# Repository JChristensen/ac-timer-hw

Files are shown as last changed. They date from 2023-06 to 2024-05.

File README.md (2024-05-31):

# AC timer  
https://github.com/JChristensen/ac-timer-hw  
README file  
Jack Christensen  
Jul-2023

## License
  
This work is licensed under the [Creative Commons Attribution-ShareAlike 4.0 International License](https://creativecommons.org/licenses/by-sa/4.0/).

## See also
[https://github.com/JChristensen/dehumid](https://github.com/JChristensen/dehumid) (firmware)  
[https://github.com/JChristensen/ac-timer-panel](https://github.com/JChristensen/ac-timer-panel)

## Construction
The project is assembled in a square metallic electrical box, 4 in. x 2⅛ in. deep (30.3 cu. in.), with ½ in. knockouts. The box acts as a heat sink for the solid state relay; use heat sink grease when fastening the SSR to the box.

See the links above for firmware and for a small PCB to facilitate mounting the LEDs and pushbutton switch.

See the bill of materials [in this repo](https://github.com/JChristensen/ac-timer-hw/blob/master/bom.csv) and at [Mouser Electronics](https://www.mouser.com/ProjectManager/ProjectDetail.aspx?AccessID=c48290707f).

## Sample assembly




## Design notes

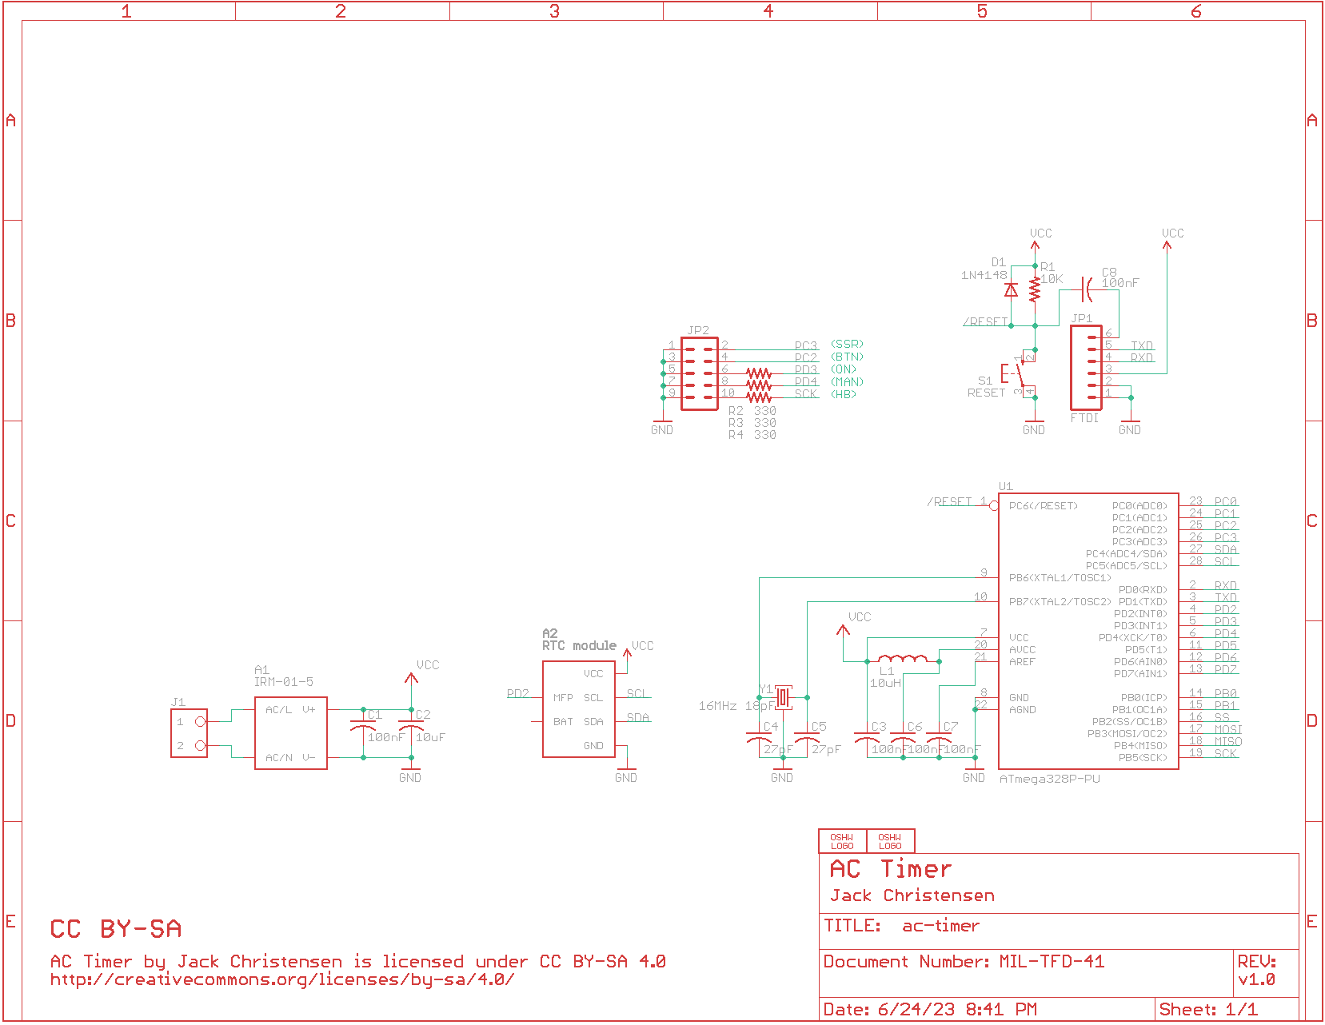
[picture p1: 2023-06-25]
schematic.png

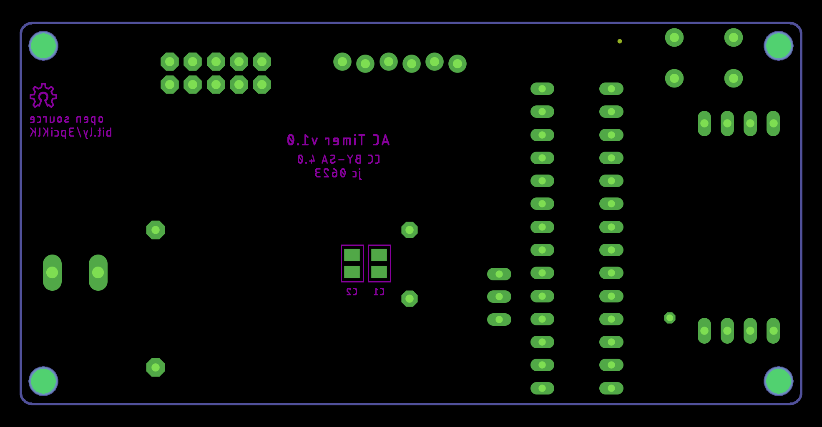
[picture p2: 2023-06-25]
bottomsilkmask.png

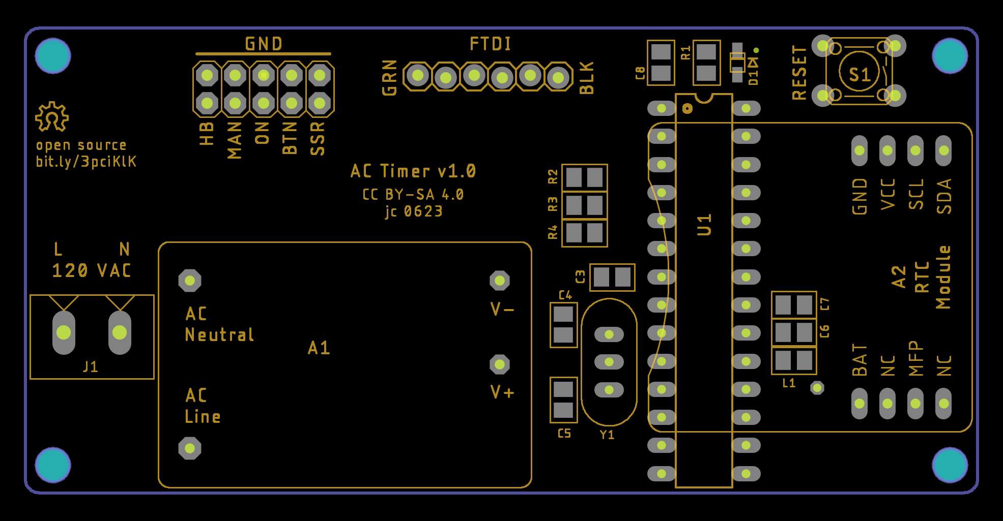
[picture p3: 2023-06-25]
topsilkmask.png

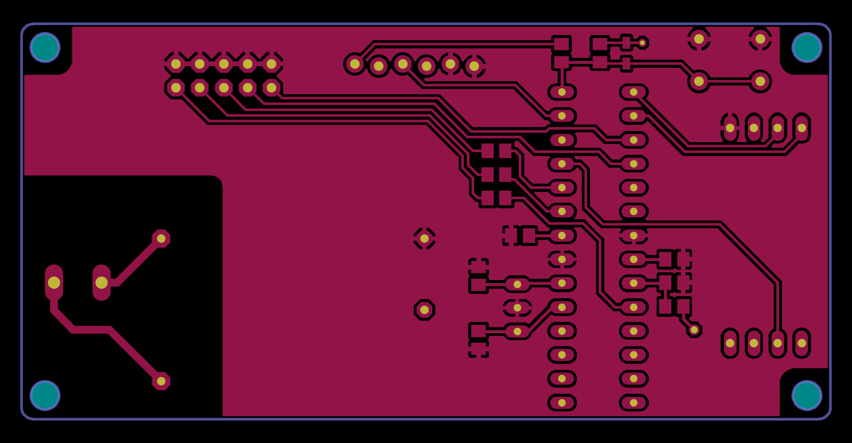
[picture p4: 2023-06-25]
toplayer.png

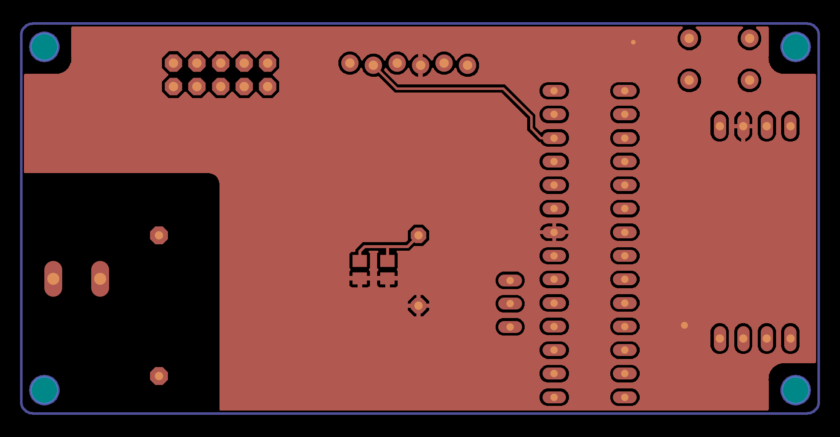
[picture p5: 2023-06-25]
bottomlayer.png

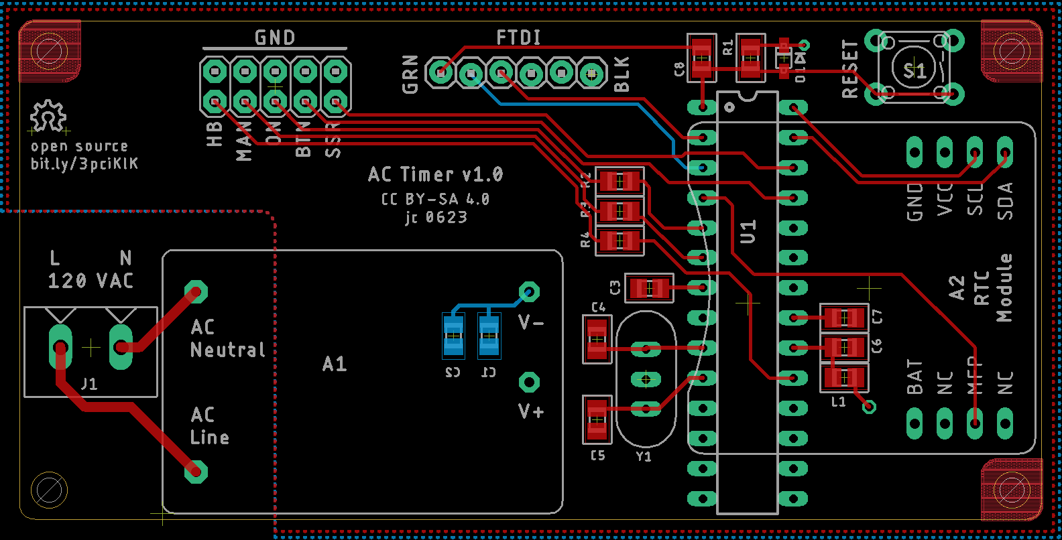
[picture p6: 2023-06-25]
board.png

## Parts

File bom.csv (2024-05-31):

AC Daily Timer
Copyright (C) 2023-2024 by Jack Christensen and licensed under CC-BY-SA-4.0.
https://www.mouser.com/ProjectManager/ProjectDetail.aspx?AccessID=c48290707f
Part # | Qty | Mouser # | Description | Manufacturer | Mfr. #
A1 | 1 | 709-IRM01-5 | AC/DC Power Module 1W 5V 200mA | MEAN WELL | IRM-01-5
A2 | 1 | n/a | Real-time clock module | JChristensen | https://github.com/JChristensen/rtc79412
C1,3,6,7,8 | 5 | 581-08053C104KAT4A | MLCC 25V 0.1uF 0805 | KYOCERA AVX | 08053C104KAT4A
C2 | 1 | 187-CL21A106KPCLQNC | MLCC 10uF 10V 0805 | Samsung Electro-Mechanics | CL21A106KPCLQNC
C4,5 | 2 | 77-VJ0805A270GXXPBC | MLCC 0805 27pF 25volts C0G 2% | Vishay | VJ0805A270GXXPW1BC
D1 | 1 | 512-1N4148WS | Small Signal Diode | onsemi | 1N4148WS
J1 | 1 | 651-1935161 | Terminal block, 2 position, 5.08mm pitch | Phoenix Contact | 1935161
JP1 | 1 |  | 2.54mm header, male, 1x6 | generic
JP2 | 1 |  | 2.54mm header, male, 2x5 | generic
L1 | 1 | 963-LBR2012T100K | Inductor 0805 10uH | TAIYO YUDEN | LBR2012T100K
R1 | 1 | 660-RK73H1JTTDD1002F | Thick Film Resistor 10k ohms | KOA Speer | RK73H1JTTDD1002F
R2,3,4 | 3 | 660-RK73H1JTTDD3300F | Thick Film Resistor 330 ohms | KOA Speer | RK73H1JTTDD3300F
S1 | 1 | 653-B3F-1020 | Tactile Button Switch | Omron | B3F-1020
U1 | 1 | 556-ATMEGA328P-PU | 8-bit Microcontroller | Microchip | ATMEGA328P-PU
Y1 | 1 | 774-ATS16B-E | Crystal, 16MHz 18pF 30ppm | CTS | ATS16B-E
 | 1 |  | Solid State Relay, 40A | SparkFun Electronics | COM-13015
 | 1 |  | Square metallic electrical box, 4 in. x 2⅛ in. deep (30.3 cu. in.), ½ in. knockouts
 | 1 |  | Cover for above box
 | 1 |  | Duplex receptacle
 | 1 |  | 14-gauge power cable
 | 1 |  | ½ in. cable clamp
 | 1 |  | Red LED, 5mm | generic
 | 1 |  | Yellow LED, 5mm | generic
 | 1 |  | Green LED, 5mm | generic
 | 1 |  | Pushbutton switch | generic | SparkFun COM-11992, Jameco 26623, or similar

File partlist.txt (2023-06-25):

Partlist

Exported from ac-timer.brd at 6/24/23 8:41 PM

EAGLE Version 9.6.2 Copyright (c) 1988-2020 Autodesk, Inc.

Assembly variant: 

Part     Value          Package       Library  Position (mm)         Orientation

A1       IRM-01-5       IRM-01        _jc      (12 0.5)              R0
A2       RTC module     RTC79412      _jc      (71.5 19.5)           R90
C1       100nF          M0805         _jc      (39.5 15.5)           MR90
C2       10uF           M0805         _jc      (36.5 15.5)           MR90
C3       100nF          M0805         _jc      (53 19.5)             R180
C4       27pF           M0805         _jc      (48.6 15.2)           R90
C5       27pF           M0805         _jc      (48.6 8.4)            R270
C6       100nF          M0805         _jc      (69.4 14.5)           R0
C7       100nF          M0805         _jc      (69.4 17)             R0
C8       100nF          M0805         _jc      (57.4 38.9)           R90
D1       1N4148         SOD-323F      _jc      (64.3 38.9)           R90
J1                      OST-TB-2-0.20 _jc      (6 14.5)              R180
JP1      FTDI           1X06_LOCK     SparkFun (48.14 37.5)          R180
JP2      M05X2PTH       AVR_ICSP      SparkFun (21.5 36.5)           R270
L1       10uH           M0805         _jc      (69.4 11.95)          R180
R1       10K            M0805         _jc      (61.5 38.9)           R90
R2       330            M0805         _jc      (50.5 28.5)           R180
R3       330            M0805         _jc      (50.5 26)             R180
R4       330            M0805         _jc      (50.5 23.5)           R180
S1       RESET          B3F-10XXOCT   _jc      (75.28 38.15)         R180
U1       ATmega328P-PU  DIL28-3       SparkFun (61.28 18.25)         R270
Y1       16MHz 18pF     RESONATOR     _jc      (52.71 11.82)         R270

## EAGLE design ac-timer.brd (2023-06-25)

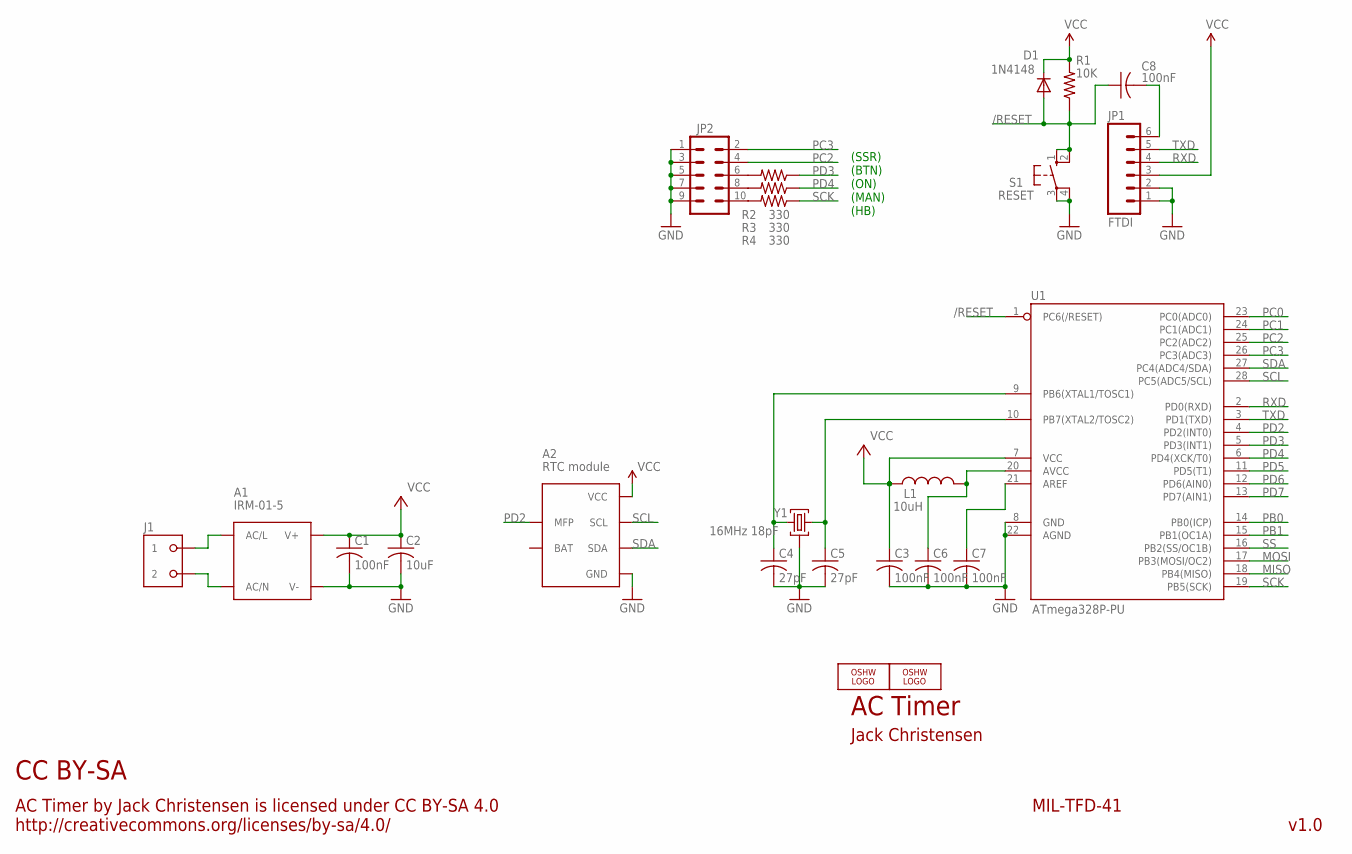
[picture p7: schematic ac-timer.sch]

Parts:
A1: IRM-01-5; IRM-01
A2: RTC module; RTC79412
C1, C3, C6, C7, C8: 100nF; M0805
C2: 10uF; M0805
C4, C5: 27pF; M0805
D1: 1N4148; SOD-323F
J1: OST-TB-20.20IN; OST-TB-2-0.20
JP1: FTDI; 1X06_LOCK
JP2: M05X2PTH; AVR_ICSP
L1: 10uH; M0805
LOGO1, LOGO2: OSHW_LOGO_8MILX0100-NT; OSHW_8X100_NOTEXT
R1: 10K; M0805
R2, R3, R4: 330; M0805
S1: RESET; B3F-10XXOCT
U1: ATmega328P-PU; DIL28-3
Y1: 16MHz 18pF; RESONATOR

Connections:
/RESET: C8.1, D1.A, R1.1, S1.1 (S), S1.2 (S1), U1.1 (PC6(/RESET))
GND: A1.V-, A2.8 (GND), C1.2, C2.2, C3.2, C4.2, C5.2, C6.2, C7.2, JP1.1, JP1.2, JP2.1, JP2.3, JP2.5, JP2.7, JP2.9, S1.3, S1.4 (P1), U1.8 (GND), U1.22 (AGND), Y1.2
MISO: U1.18 (PB4(MISO))
MOSI: U1.17 (PB3(MOSI/OC2))
unnamed: JP2.10, R4.2
unnamed: JP2.8, R3.2
unnamed: JP2.6, R2.2
unnamed: C5.1, U1.10 (PB7(XTAL2/TOSC2)), Y1.3
unnamed: C6.1, L1.2, U1.20 (AVCC)
unnamed: C4.1, U1.9 (PB6(XTAL1/TOSC1)), Y1.1
unnamed: C7.1, U1.21 (AREF)
unnamed: A1.AC/N, J1.P$2 (2)
unnamed: A1.AC/L, J1.P$1 (1)
PB0: U1.14 (PB0(ICP))
PB1: U1.15 (PB1(OC1A))
PC0: U1.23 (PC0(ADC0))
PC1: U1.24 (PC1(ADC1))
PC2: JP2.4, U1.25 (PC2(ADC2))
PC3: JP2.2, U1.26 (PC3(ADC3))
PD2: A2.3 (MFP), U1.4 (PD2(INT0))
PD3: R2.1, U1.5 (PD3(INT1))
PD4: R3.1, U1.6 (PD4(XCK/T0))
PD5: U1.11 (PD5(T1))
PD6: U1.12 (PD6(AIN0))
PD7: U1.13 (PD7(AIN1))
RST: C8.2, JP1.6
RXD: JP1.4, U1.2 (PD0(RXD))
SCK: R4.1, U1.19 (PB5(SCK))
SCL: A2.6 (SCL), U1.28 (PC5(ADC5/SCL))
SDA: A2.5 (SDA), U1.27 (PC4(ADC4/SDA))
SS: U1.16 (PB2(SS/OC1B))
TXD: JP1.5, U1.3 (PD1(TXD))
VCC: A1.V+, A2.7 (VCC), C1.1, C2.1, C3.1, D1.K, JP1.3, L1.1, R1.2, U1.7 (VCC)

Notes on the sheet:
AC Timer
Jack Christensen
AC Timer by Jack Christensen is licensed under CC BY-SA 4.0 http://creativecommons.org/licenses/by-sa/4.0/
CC BY-SA
v1.0
MIL-TFD-41
(SSR) (BTN) (ON) (MAN) (HB)

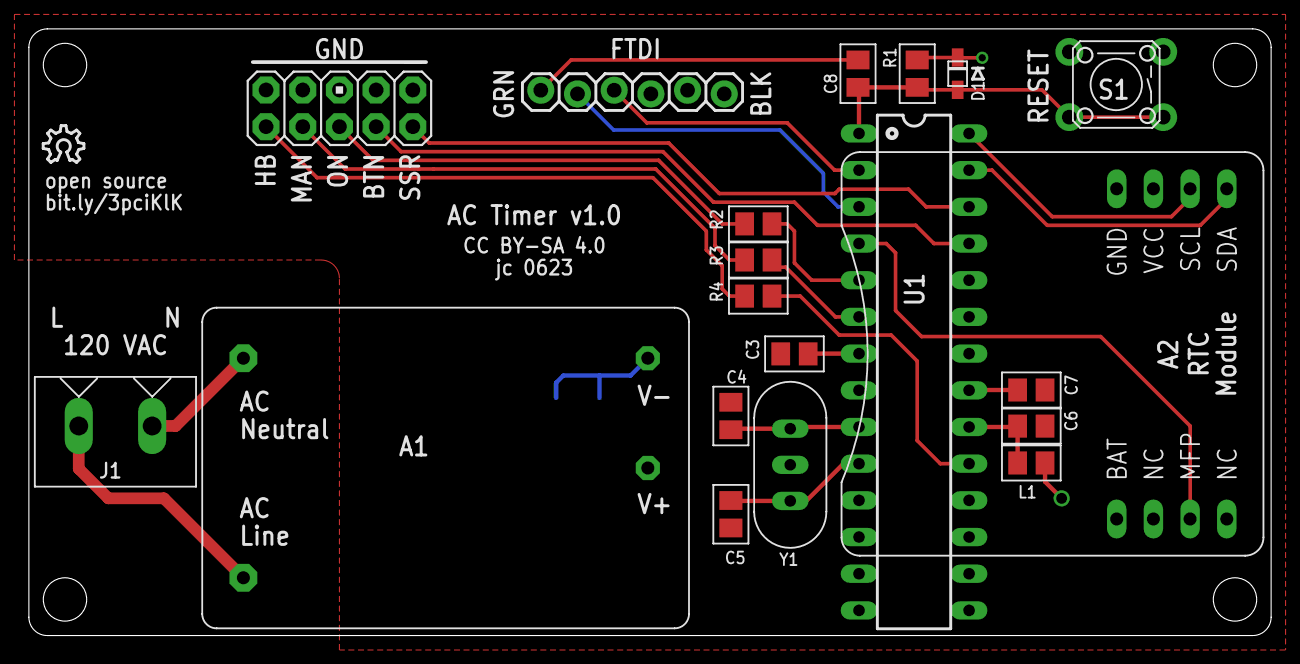
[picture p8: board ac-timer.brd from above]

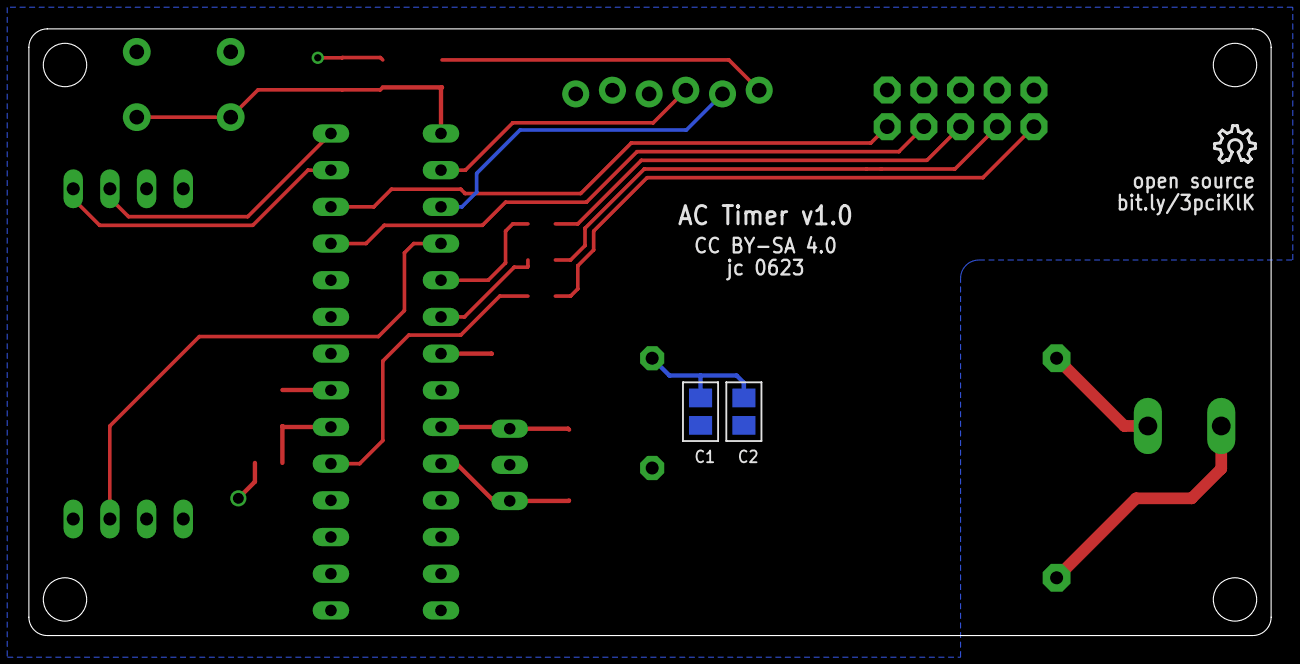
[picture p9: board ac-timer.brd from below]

Board: 2 copper layers, 86.0 x 42.0 mm, 24 parts (3 on the bottom side), 23 nets.

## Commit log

2023-06-23 Initial commit.
    [ac-timer.brd, ac-timer.sch]
2023-06-23 Rotate AC input terminal block.
    [ac-timer.brd]
2023-06-24 Production candidate 01
    [ac-timer.brd, ac-timer.sch]
2023-06-24 Small routing and silk tweaks.
    [ac-timer.brd, ac-timer.sch]
2023-06-25 Widen AC traces.
    [ac-timer.brd, ac-timer.sch]
2024-05-31 Add README, LICENSE, BOM, gerbers.zip
    [bom.csv, bom.ods]

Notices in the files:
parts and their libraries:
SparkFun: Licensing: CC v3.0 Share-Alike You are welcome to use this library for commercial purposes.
